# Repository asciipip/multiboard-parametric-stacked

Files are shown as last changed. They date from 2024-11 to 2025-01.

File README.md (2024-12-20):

# Stacked Parametric Multiboard Tiles

This is an [OpenSCAD][] file for generating arbitrary stacked
[Multiboard][] tiles.

  [OpenSCAD]: https://openscad.org/
  [Multiboard]: https://www.multiboard.io/

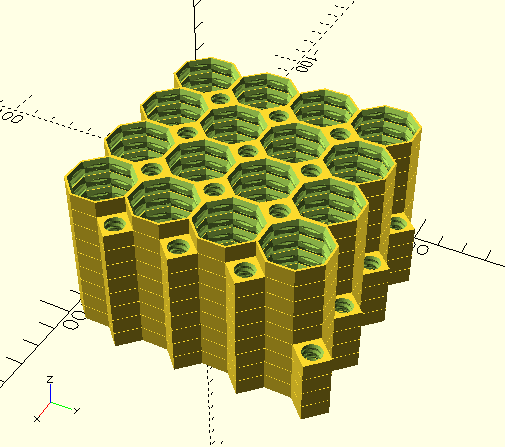
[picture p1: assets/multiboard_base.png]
Rendering of a stack of Multiboard tiles


## Usage

Use the `multiboard_base.scad` file and set the following parameters:

 * `x_cells` – The number of cells (large holes) in the X direction
 * `y_cells` – The number of cells in the Y direction
 * `core_tiles` – The number of core tiles to generate; these tiles have
   teeth in both the X and Y direction
 * `side_tiles` – The number of side tiles to generate; these tiles have
   teeth only in the X direction
 * `corner_tiles` – The number of corner tiles to generate; these tiles
   have no teeth
 * `layer_thickness` – The layer thickness you will be using to print the
   tiles

If you want the side and corner tiles to have different dimensions from
the corner tiles, you can also change the advanced settings, which should
be fairly self-explanatory:

 * `side_x_cells`
 * `side_y_cells`
 * `corner_x_cells`
 * `corner_y_cells`

The default value for those advanced settings is "0", which means to use
the `x_cells` and `y_cells` values for the tile.

Render the file and save to an STL.

In your slicer, make sure you've enabled ironing of top surfaces.  In
addition to that, make sure you're using the recommended Multiboard
printing parameters (3-line thick walls, 15% infill).

After printing, it may take a little work to separate the tiles.  The
author has had the best luck by pulling apart the corner closest to the
origin (i.e. furthest from the tile teeth) and then working along the tile
from there.

Multiboard has a video about how to print stacks:
[Multiboard: What Is Stack 3D Printing](https://youtu.be/xs2urfM0MRM).

## Stack Printing Drawbacks

Stack-printed tiles will have one side that's smooth and the other side
(the one on the bottom during printing) will be a bit rough.  This
shouldn't be a problem if you're only planning on using one side of the
files (e.g. if you're mounting them on a wall).

You can print an entire set of tiles at once _as long as the tiles are
square_.  If you're tiling non-square tiles, you'll need at least two
separate stacks: one stack with the core tiles, the top (or bottom) side
tiles, and the corner tile; the other stack with the right (or left) side
tiles.  That's because this generator always puts the side tile's teeth on
the right side, and the right (or left) side tiles need the teeth on top.
For the right (or left) side tiles, swap the tile X and Y dimensions in
the file parameters and just print side tiles.

Stack-printed tiles can be difficult to separate.  Ironing the tile
surfaces is required, and you should have your printer calibrated as
precisely as possible.  If the stacks aren't working for you and you have
a multi-extruder printer, you might consider the [Multiboard Parametric
Extended][] model from Uno.

  [Multiboard Parametric Extended]: https://www.printables.com/model/882280-multiboard-parametric-extended-openscad

The author has only really tested this model with a 0.2 mm layer height.
Multiboard components in general are designed to be printed with 0.2 mm
layers.  Although other layer heights _should_ work with this model,
they're less-guaranteed.  Feedback on others' experiences of printing with
different thicknesses would be appreciated.  Note also that the model
assumes all layers have equal heights (as opposed to using a
different thickness for the first layer).

## Tile Stack Sizing

To get the width of a tile, multiply the number of cells by 25 mm and then
add 8 mm for the teeth.  Each layer is 6.6 mm high, when printed with a
0.2 mm layer thickness.

A printer with a 220×220×250 mm print area can print up to 37 stacked 8×8
tiles.

## Stacks of Arbitrary Tiles

The `arbitrary_stack.scad` file can be used to create a stack of tiles
with arbitrary shapes and dimensions.  You need to put the tile
definitions in the `tiles` array.  Tile definitions can include lists of
cells to omit from the generated model.

See the comment at the top of the file for more information.

## Tile Generating Program

There's a small program in the repository to generate STLs for the tiles
needed to cover a given area.  Run `generate-stacks.py --help` for usage
information.

You need to have `openscad` in your path for the STL generation to work.
You can also pass the `--no-stl` parameter to just display the tiles that
could be used to cover the area.

For example, if you had an area 431 mm by 717 mm, you could run:

    generate-stacks.py -w 431 -h 717

Which would print the following before generating the tile stacks described:

    The parameters for the board are:
    
      Area dimensions: 431.00×717.00 mm
      Board dimensions: 17×28 (425×700 mm)
      Base tile size: 6×7
      Board tile dimensions: 3×4
    
    2 stacks will be printed:
    
      Stack 1 [Stack-6x6x7_core-2x6x7_top-5x7_corner.stl]:
        6 Core 6×7 tiles
        2 Top Side 6×7 tiles
        1 Corner 5×7 tile
    
      Stack 2 [Stack-3x5x7_right.stl]:
        3 Right Side 5×7 tiles

Also of note is the `--dxf` parameter you can pass to generate a DXF file
of the board layout.  The author uses these files as bases for detailed
project planning.  You will need to have the [ezdxf][] Python module
installed.

  [ezdxf]: https://ezdxf.mozman.at/

## Credits

[Multiboard][] was designed by Jonathan of [Keep Making][].

  [Keep Making]: https://www.youtube.com/@Keep-Making

These files are based on Victor Zag's [multiboard-parametric][] project.
Victor did all the really important initial work.

  [multiboard-parametric]: https://github.com/shaggyone/multiboard-parametric

## License

This model is derived from Multiboard files and is covered by the
[Multiboard License][].  A copy is available in the `LICENSE.md` file.

  [Multiboard License]: https://www.multiboard.io/license

Note in particular that the license restricts commercial use of derived
works.

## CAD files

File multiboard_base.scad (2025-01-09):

// Model to generate stacks of Multiboard tiles for assembly into large
// boards.

/* [Tile Size] */

// Number of cells along the X axis
x_cells = 4;
// Number of cells along the y axis
y_cells = 4;

/* [Tile Counts] */

// Number of core tiles (pegboard holes on the right and top)
core_tiles = 4;
// Number of side tiles (pegboard holes only on the top)
side_tiles = 4;
// Number of corner tiles (no pegboard holes)
corner_tiles = 1;

/* [Print Settings] */

// Your slicer's layer thickness in millimeters; 0.2 mm is strongly recommended
layer_thickness = 0.2;

/* [Per-Shape Tuning] */

// X size of the side tiles; "0" means to use the main x_cells setting
side_x_cells = 0;
// Y size of the side tiles; "0" means to use the main y_cells setting
side_y_cells = 0;
// X size of the corner tiles; "0" means to use the main x_cells setting
corner_x_cells = 0;
// Y size of the corner tiles; "0" means to use the main y_cells setting
corner_y_cells = 0;


// No user-servicable parts below this line.

// Actual tile dimensions
real_side_x_cells = side_x_cells > 0 ? side_x_cells : x_cells;
real_side_y_cells = side_y_cells > 0 ? side_y_cells : y_cells;
real_corner_x_cells = corner_x_cells > 0 ? corner_x_cells : x_cells;
real_corner_y_cells = corner_y_cells > 0 ? corner_y_cells : y_cells;

// Dimension validation
assert(layer_thickness > 0, "Layer thickness must be larger than zero");
assert(min(core_tiles, side_tiles, corner_tiles) >= 0, "Can't make negative numbers of tiles");
assert(min(x_cells, y_cells, real_side_x_cells, real_side_y_cells, real_corner_x_cells, real_corner_y_cells) >= 1,
       "Not enough cells to actually make a tile")
assert(real_side_x_cells <= x_cells, "Side tile X value larger than core tile X value");
assert(real_side_y_cells <= y_cells, "Side tile Y value larger than core tile Y value");
assert(real_corner_x_cells <= real_side_x_cells, "Corner tile X value larger than side tile X value");
assert(real_corner_y_cells <= real_side_y_cells, "Corner tile Y value larger than side tile Y value");


// All measurements are based on the Multiboard tile component remixing
// files at https://than.gs/m/994681, uploaded 2024-01-19.

// Main dimensions
cell_size = 25+0;
height = 6.4+0;
default_fn = 32+0;

// Single tile outer dimensions
side_l = cell_size/(1+2*cos(45));
size_l_offset = (cell_size - side_l)/2;

// Single tile hole dimensions

// The "thick" part is the middle of the hole, where the sides are thicker
// than the top and bottom.
multihole_thick_height = 2.4+0;
multihole_thick_size = 21.4+0;
multihole_thin_size = 23.4+0;

// The multihole is an octagon.  We'll get OpenSCAD to generate that by
// telling it to make a circle with a radius equal to the outer corners of
// the hole, but with only eight sides.
multihole_thick_side_l = multihole_thick_size/(1+2*cos(45));
multihole_thick_bound_circle_d = multihole_thick_side_l/sin(22.5);
multihole_thin_side_l = multihole_thin_size/(1+2*cos(45));
multihole_thin_bound_circle_d = multihole_thin_side_l/sin(22.5);
multihole_base_fn = 8+0;

// The threads are formed using a spiral with a trapezoidal cross-section.
// `d1` is the outer diameter of the spiral and `d2` is the inner
// diameter.  `h1` is the height of the outer wall and `h2` is the height
// of the inner wall.  `pitch` has its usual meaning: the distance from
// one thread peak (or valley) to the next immediately above or below it.
multihole_thread_d1 = 22.6+0;
multihole_thread_d2 = multihole_thick_size+0;
multihole_thread_h1 = 0.5+0;  // Height of outer thread
multihole_thread_h2 = 1.583+0;  // Height of thread at inner cylinder
multihole_thread_pitch = 2.5+0;

peg_hole_thick_height = 2.9+0;
peg_hole_thick_size = 6+0;
peg_hole_thin_size = 7.5+0;

peg_hole_thread_pitch = 3+0;
peg_hole_thread_d1 = 7+0;
peg_hole_thread_d2 = peg_hole_thick_size+0;
peg_hole_thread_h1 = 0.77+0;
peg_hole_thread_h2 = peg_hole_thread_pitch-0.5;

// Distance between stacked layers.  There should be at least one empty
// layer between adjacent tiles.  If the height of a single tile is not
// evenly divisible by the layer thickness, we might need more space than
// just the layer thickness to make sure that happens.
layer_separation = abs(-height % layer_thickness) + layer_thickness;
stack_height = height + layer_separation;


// Here's the stack

multiboard_tile_stack(core_tiles, x_cells, y_cells, right_peg_holes=true, top_peg_holes=true);

translate([0, 0, stack_height * core_tiles])
  multiboard_tile_stack(side_tiles, real_side_x_cells, real_side_y_cells, right_peg_holes=false, top_peg_holes=true);

translate([0, 0, stack_height * (core_tiles + side_tiles)])
  multiboard_tile_stack(corner_tiles, real_corner_x_cells, real_corner_y_cells, right_peg_holes=false, top_peg_holes=false);


// Now, all the modules the stack uses

module multiboard_tile_stack(tile_count, x_cells, y_cells, right_peg_holes, top_peg_holes, exceptions) {
  if (tile_count > 0)
    for (level = [0:tile_count-1])
      translate([0, 0, stack_height * level])
        multiboard_tile(x_cells, y_cells, right_peg_holes, top_peg_holes, exceptions);
}


module multiboard_tile(x_cells, y_cells, right_peg_holes, top_peg_holes, exceptions) {
  for (i=[0:x_cells-1])
    for (j=[0:y_cells-1])
      // A pretty good rule of thumb is that there should be a peg hole
      // between every two diagonally adjacent multiholes.
      let (render_this_cell = cell_at_coords(i, j, x_cells, y_cells, right_peg_holes, top_peg_holes, exceptions),
           has_diagonal_neighbor = cell_at_coords(i + 1, j + 1, x_cells, y_cells, right_peg_holes, top_peg_holes, exceptions),
           has_adjacent_neighbors =
             cell_at_coords(i + 1, j, x_cells, y_cells, right_peg_holes, top_peg_holes, exceptions) &&
             cell_at_coords(i, j + 1, x_cells, y_cells, right_peg_holes, top_peg_holes, exceptions))
        translate([i*cell_size, j*cell_size, 0])
          if (render_this_cell) {
            multiboard_cell(with_peg_hole=has_diagonal_neighbor || has_adjacent_neighbors);
          } else if (has_adjacent_neighbors) {
            standalone_peg_hole();
          }
}


module multiboard_cell(with_peg_hole) {
  $fn=default_fn;
  difference() {
    multiboard_cell_base(with_peg_hole);
    translate([cell_size/2, cell_size/2, 0])
      multihole();
    if (with_peg_hole)
      translate([cell_size, cell_size, 0])
        peg_hole();
  }
}


module multiboard_cell_base(with_peg_hole) {
  base_points = [
    [cell_size - size_l_offset, cell_size],
    [size_l_offset,             cell_size],
    [0,                         cell_size - size_l_offset],
    [0,                         size_l_offset],
    [size_l_offset,             0],
    [cell_size - size_l_offset, 0],
    [cell_size,                 size_l_offset],
    [cell_size,                 cell_size - size_l_offset],
  ];
  points = with_peg_hole
    ? [
       each base_points,
       [cell_size + size_l_offset, cell_size],
       [cell_size,                 cell_size + size_l_offset],
      ]
    : base_points;
  linear_extrude(height)
    polygon(points);
}


module standalone_peg_hole() {
  $fn=default_fn;
  points = [
    [cell_size,                 cell_size - size_l_offset],
    [cell_size + size_l_offset, cell_size],
    [cell_size,                 cell_size + size_l_offset],
    [cell_size - size_l_offset, cell_size],
  ];
  difference() {
    linear_extrude(height)
      polygon(points);
    translate([cell_size, cell_size, 0])
      peg_hole();
  }
}


module multihole() {
  multihole_base($fn=multihole_base_fn);
  // The rotation here isn't strictly necessary, but it makes the threads
  // line up with the Multiboard STEP files, which, in turn, makes
  // debugging easier.
  if (!$preview)
    rotate(-170, [0, 0, 1])
      multihole_threads();
}


module multihole_base() {
  // Rotation needed to align the hole sides with the cell's outer sides.
  rotate(22.5, [0, 0, 1])
    tapered_hole_base(
      multihole_thin_bound_circle_d / 2,
      multihole_thick_bound_circle_d / 2,
      multihole_thick_height);
}


module multihole_threads() {
  translate([0, 0, -multihole_thread_h2/2])
    trapz_thread(multihole_thread_d1, multihole_thread_d2,
                 multihole_thread_h1, multihole_thread_h2,
                 thread_len=height+multihole_thread_h2,
                 pitch=multihole_thread_pitch);
}


module peg_hole() {
  // The rotation here isn't strictly necessary, but it makes the threads
  // line up with the Multiboard STEP files, which, in turn, makes
  // debugging easier.
  rotate(-129, [0, 0, 1]) {
    peg_hole_base();
    if (!$preview)
      peg_hole_threads();
  }
}


module peg_hole_base() {
  tapered_hole_base(
    peg_hole_thin_size / 2,
    peg_hole_thick_size / 2,
    peg_hole_thick_height);
}
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

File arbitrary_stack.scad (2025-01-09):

/* [Tile Definitions] */

// Array of tile shapes.
//
// Each array element should be:
//   [count, x_cells, y_cells, shape, exceptions]
//
// Valid shapes are:
//  * "core"
//  * "side" (for a left or right side with the teeth on the top)
//  * "rotated side" (for a top or bottom side with the teeth on the right)
//  * "corner"
//
// The exceptions element is optional.  If present, it should be a list of
// x, y pairs.  Each pair indicates a cell that should *not* be generated
// in the model.  Cells are zero-indexed.  [0, 0] is the cell in the lower
// left corner of the tile.  Note that you can add exceptions for the
// cells in the row and column just past the dimensions of a tile; this
// will cause some of the teeth on the edge of the tile to be suppressed
// in the same way they would be if cells internal to the tile were being
// omitted.
//
// Warning: This model will create whatever you tell it to.  It's up to
// you to make sure your tiles are all supported.

tiles = [
  [4, 4, 4, "core"],
  [3, 4, 4, "side"],
  [2, 3, 4, "rotated side"],
  [1, 3, 3, "corner", [[1, 1], [2, 1]]],
];

/* [Print Settings] */

// Your slicer's layer thickness in millimeters; 0.2 mm is strongly recommended
layer_thickness = 0.2;


// No user-servicable parts below this line.

use <multiboard_base.scad>

// `use` doesn't pull in variables, so we need to redefine the ones we
// need.
cell_size = 25+0;
height = 6.4+0;
stack_height = height + abs(-height % layer_thickness) + layer_thickness;


module tile_group(offset, tile_params) {
  count = tile_params[0];
  x_cells = tile_params[1];
  y_cells = tile_params[2];
  shape = tile_params[3];
  exceptions = tile_params[4];
  assert(x_cells >= 1, "X dimension must be at least 1");
  assert(y_cells >= 1, "Y dimension must be at least 1");
  translate([0, 0, offset * stack_height])
    for (level = [0:1:count-1])
      translate([0, 0, level * stack_height])
        generic_tile(x_cells, y_cells, shape, exceptions);
}


module generic_tile(x_cells, y_cells, shape, exceptions) {
  if (shape == "core")              {multiboard_tile(x_cells, y_cells, right_peg_holes=true, top_peg_holes=true, exceptions=exceptions);}
  else if (shape == "side")         {multiboard_tile(x_cells, y_cells, right_peg_holes=false, top_peg_holes=true, exceptions=exceptions);}
  else if (shape == "rotated side") {multiboard_tile(x_cells, y_cells, right_peg_holes=true, top_peg_holes=false, exceptions=exceptions);}
  else if (shape == "corner")       {multiboard_tile(x_cells, y_cells, right_peg_holes=false, top_peg_holes=false, exceptions=exceptions);}
  else {
    assert(false, "Unknown tile shape");
  }
}


offsets = [ for (o = 0, i = 0; i < len(tiles); o = o + tiles[i][0], i = i + 1) o ];

for ( i = [0:1:len(tiles)-1] )
  tile_group(offsets[i], tiles[i]);

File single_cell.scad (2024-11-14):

/* Generates a single tile cell, with multihole and peg hole.
 *
 * This is mostly for debugging.
 */

use <multiboard_base.scad>

// This should be the same alignment as the .STEP remixing files.
translate([-12.5, -12.5, 0])
multiboard_cell(true);

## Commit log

2024-10-19 Stack tiles
    [multiboard_base.scad]
2024-10-20 Add comments for the OpenSCAD customizer
    [multiboard_base.scad]
2024-10-20 Better hide the non-parameter variables from the customizer
    [multiboard_base.scad]
2024-10-23 Allow for different side and corner tile dimensions
    [multiboard_base.scad]
2024-10-23 Separate file to generate arbitrary tile stacks
    At the cost of a less-friendly user interface.
    [arbitrary_stack.scad]
2024-10-23 Clarify that `multiboard_base.scad` is the main file to use
    [multiboard_base.scad]
2024-10-23 Fix an edge case
2024-10-31 Rework the model to be more efficient
    The new approach works by creating two cell shapes--one with a small hole
    and one without--and then just repeating those shapes enough times to get
    a tile.
    OpenSCAD seems to like this approach a lot better. In a lot of tests, it
    cut rendering time almost in half.
    This should also make it easier to render non-rectangular tiles in the
    future.
    [arbitrary_stack.scad, multiboard_base.scad]
2024-10-31 Consolidate corner and core cell types
    Now the cell module just takes a parameter indicating whether or not to
    add a pegboard hole in the corner.
    [arbitrary_stack.scad, multiboard_base.scad]
2024-11-01 Factor out some directives common to all substacks
    [multiboard_base.scad]
2024-11-03 Flare the ends of the peg hole, just like the STEP models
    Note that older Multiboard tile STLs have straight-sided peg holes, like
    this model used to. At some point, the design was revised, the STEP files
    were updated, and all new models with peg holes got the flares, but the
    old STLs were left as they were.
    I also renamed a bunch of variables to make it easier for me to track what
    everything was for. This is mixing two different changes, but the new
    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
    [multiboard_base.scad]
2024-11-03 Document the multihole parameters a little more
    [multiboard_base.scad]
2024-11-03 For testing purposes, a file with just a single Multiboard cell
    [single_cell.scad]
2024-11-03 Exclude from customizer
    [multiboard_base.scad]
2024-11-04 Align the OpenSCAD and STEP multihole threads, too
    [multiboard_base.scad]
2024-11-04 This appears to be a more correct value
    [multiboard_base.scad]
2024-11-04 Update the rendered image to reflect the current design
    Even though the differences from the old image are pretty minor.
2024-11-14 More comments
    [multiboard_base.scad, single_cell.scad]
2024-11-14 Factor out the commonalities to the two tapered holes
    [multiboard_base.scad]
2024-11-14 Factor out common $fn usage
    [multiboard_base.scad]
2024-12-09 Allow individual cells to be omitted from the generated tiles
    [arbitrary_stack.scad, multiboard_base.scad]
2024-12-09 Do the right thing for pegboard holes adjacent to omitted cells
    [arbitrary_stack.scad, multiboard_base.scad]
2024-12-09 Clean up the peg hole logic a little
    [multiboard_base.scad]
2024-12-18 Hide the threads in preview mode
    This helps speed up model viewing before rendering.
    [multiboard_base.scad]
2024-12-20 Instead of a --dry-run parameter, use --stl/--no-stl
2024-12-20 Draw the tile holes on the DXF output
2025-01-09 Use "side" in the same way Multiboard official tiles do
    [arbitrary_stack.scad, multiboard_base.scad]
